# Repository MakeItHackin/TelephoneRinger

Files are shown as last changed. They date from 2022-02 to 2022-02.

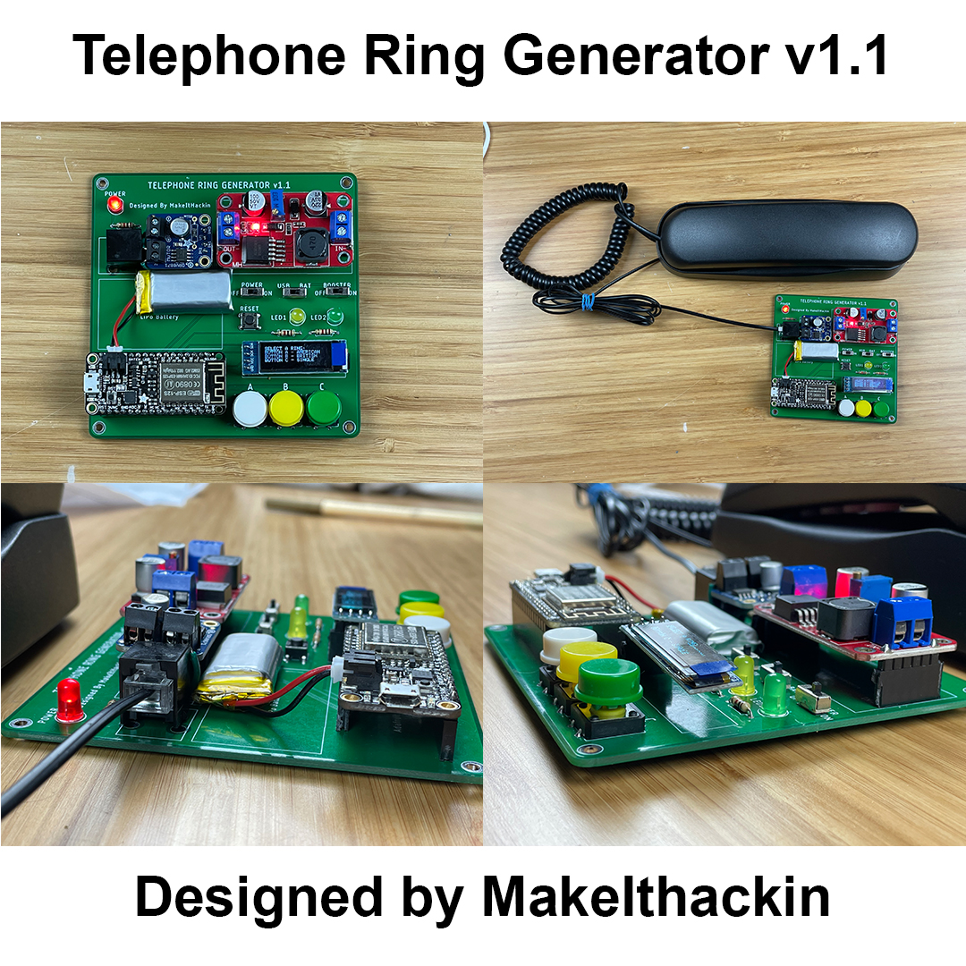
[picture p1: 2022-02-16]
TelephoneRingerV1.jpg

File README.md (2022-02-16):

# TelephoneRinger

This is a work in progress.... updates and more links to come!
If you have any suggestions, plase let me know by opening an Issue

Project offered under Attribution 4.0 International (CC BY 4.0) License.
  
Not all phone use the same amount of voltage/current to ring.  Seems like the really old phones may require higher wattage and this board may or may not ring them.  
  
BILL OF MATERIALS:
Adafruit Feather (Tested with RP2040, M0 Express, 32u4 Basic, and ESP8266 HUZZAH)  
LEDs 5mm - 3  
RESISTORS 1k - 3  
RJ-11 JACK - 1  
DRV8871 MOTOR CONTROLLER - 1  (https://www.adafruit.com/product/3190)  
XL6019 BOOST CONVERTER - 1  
SWITCHES - 3  
6mm BUTTON - 1  
12mm BUTTON - 3  
  
OPTIONAL:  
RESISTORS 10k - 3  
SSD1306 OLED (i2c) - 1  
FEMALE HEADERS FOR MODULES  
MALE HEADERS FOR MODULES  
LIPO BATTERY - 1
ADAFRUIT FEATHER WING  
TELEPHONE RING GENERATOR PCB

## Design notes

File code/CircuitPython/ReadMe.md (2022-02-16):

CircuitPython  
Tested Successfully on a Adafruit Feather RP2040  

Testing partially failed on Adafruit Feather M0 Express.  I could get the Telephone Ringer to work, but not in addition to the OLED.  I believe this occured from an out-of-memory error.  There's a variable to disable the OLED in the code.

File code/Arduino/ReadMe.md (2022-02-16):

Arduino code tested on Arduino build 1.8.13  
Optional variables to include an OLED Display (SSD1306 used in example) and Adafruit IO to remotely control ringer  

Tested on:  
Adafruit Feather Huzzah ESP8266  
Adafruit Feather 32u4 Basic  
Adafruit Feather M0 Express

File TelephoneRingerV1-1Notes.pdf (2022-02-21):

# Telephone Rigner v1.1 Notes

Ground was not connected on Feather Footprint, so after soldering Feather (or headers), use a wire and solder to the GND pin on the feather (4th from the right as shown) and connect it to any other Ground point on the board. (fixed in v1.2)
If your Feather does not have pull-up resistors on the appropriate button pins, you’ll need to solder one between that pin and VCC (fixed in v1.2)
If you don’t want to “commit” the modules to the PCB, use Female Headers as shown for the components. That way, you can swap them out later!
Photo of board bottom shows solder bridging on RJ-11 jack. This was intentional because a different jack was used than antipated. If you received a board, you should have the correct jack and no solder bridging is required.

XL6019 Board requires you to adjust the output voltage with the potentiometer. Test with a multimeter to see output. You should be able to get around 40VDC from when power is coming from the USB port.
POWER ON/OFF button only commands the Feather. It does not turn off power to the XL6019. USB/BAT selects either the USB or BAT power to send to the XL6019.
BOOSTER ON/OFF dis BOOSTER ON/OFF disconnects the USB/BAT power from entering the XL6019.
RESET is connected to RST pin of the Feather
Schematics PCB files for v1.2 are on github and the PCB will be released in March 2022

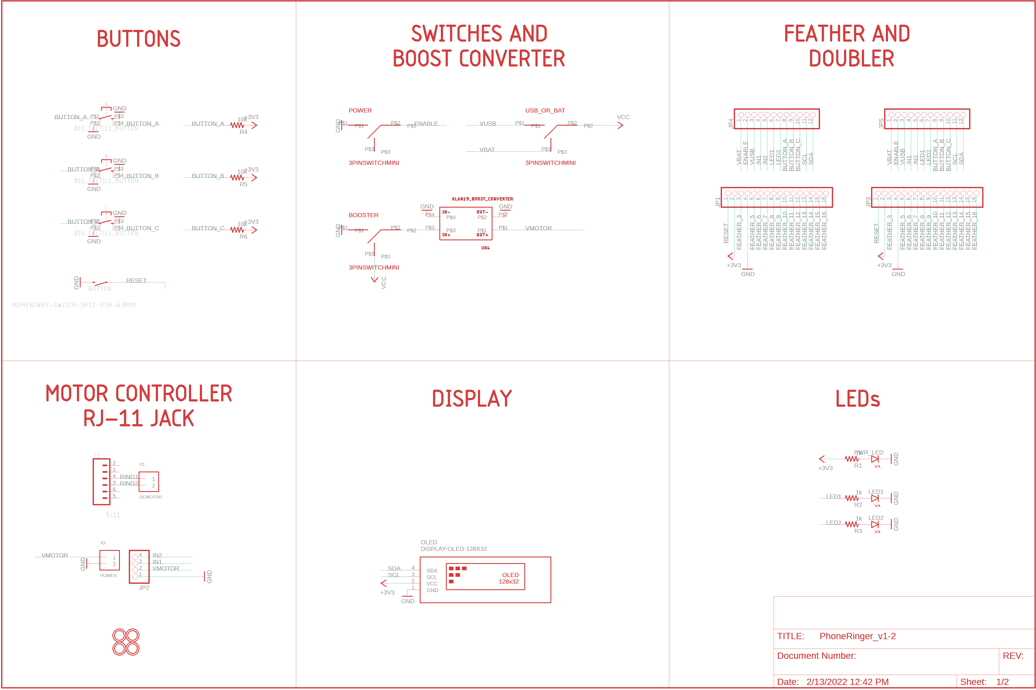
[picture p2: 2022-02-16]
PCBFiles/TelephoneRingerV1.2Schematic.png

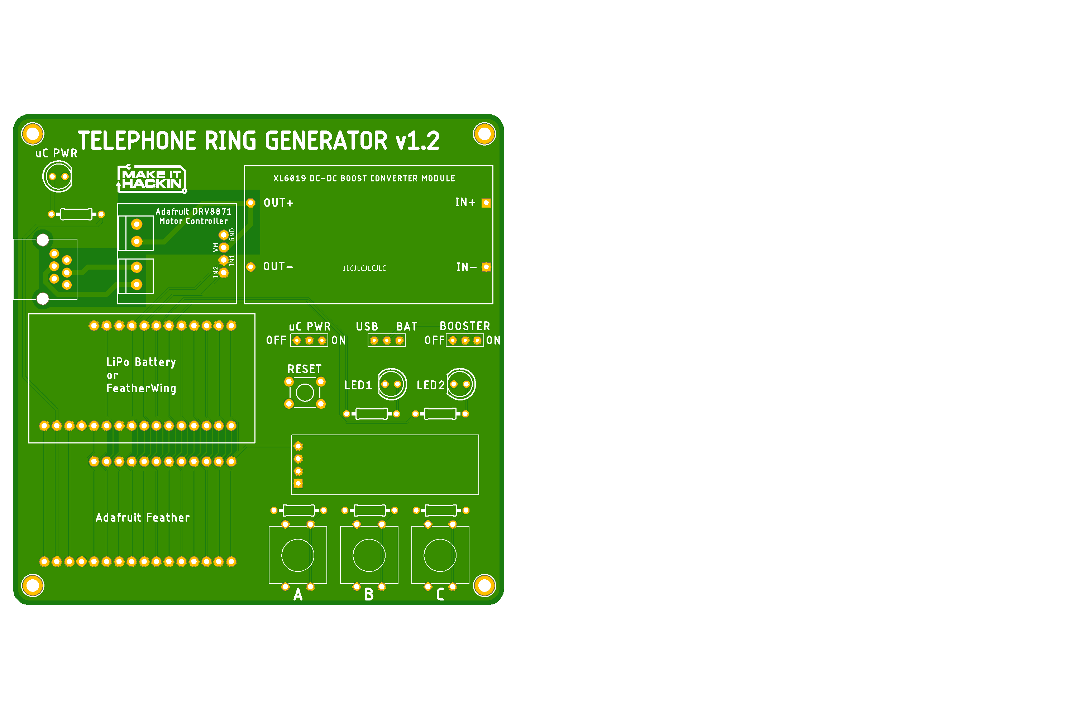
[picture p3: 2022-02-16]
PCBFiles/PhoneRinger_v1-2.png

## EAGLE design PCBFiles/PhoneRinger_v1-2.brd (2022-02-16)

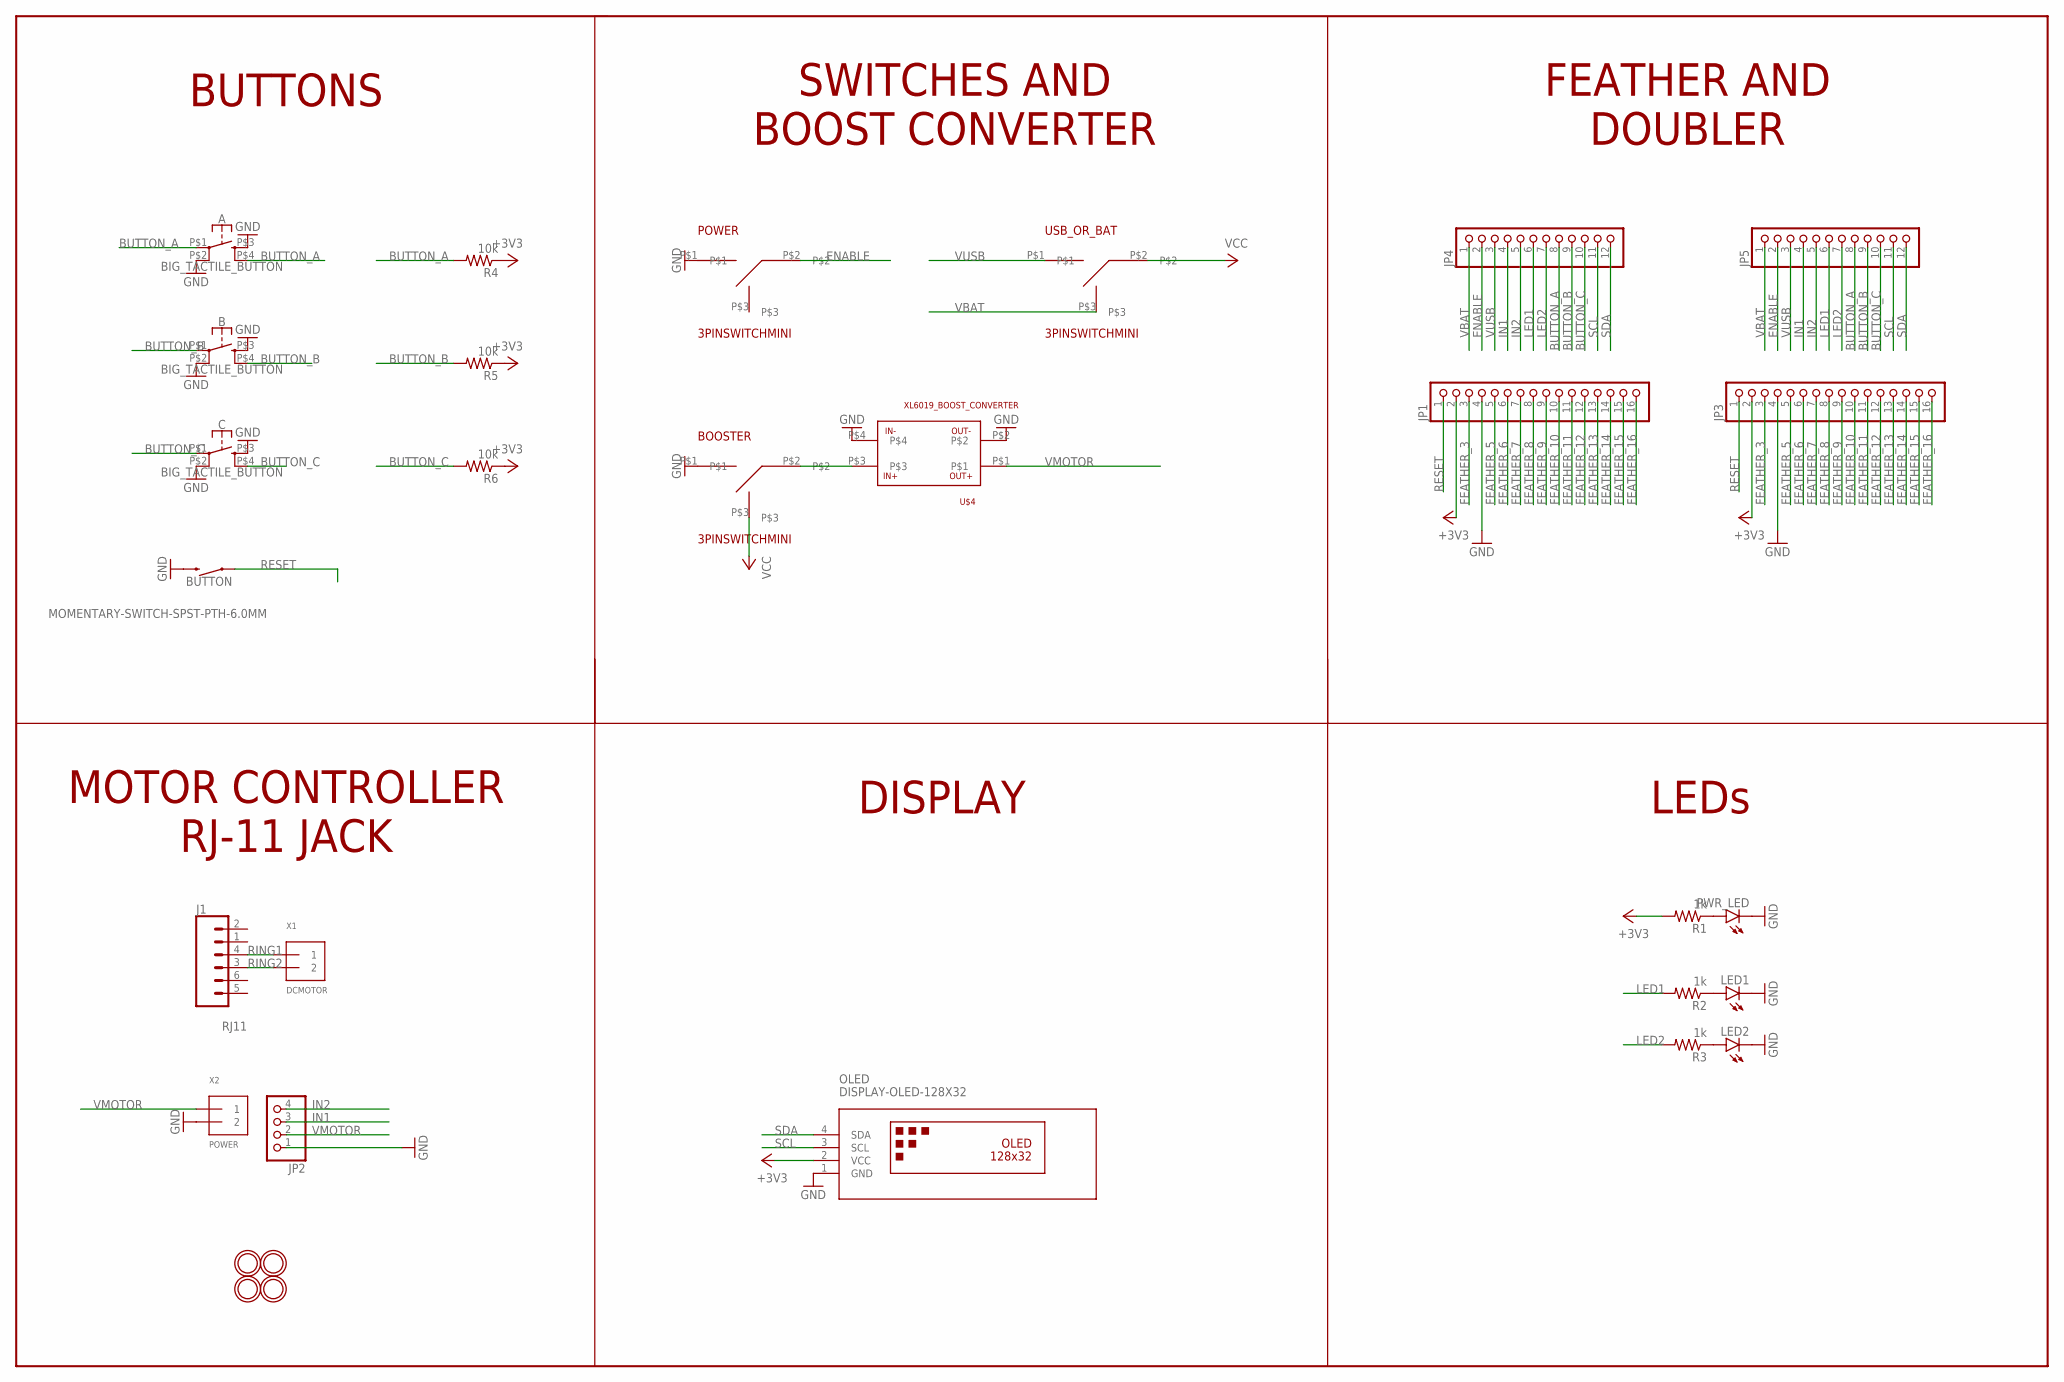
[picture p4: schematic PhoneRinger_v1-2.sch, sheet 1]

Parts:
A: BIG_TACTILE_BUTTON; BIG_TACTILE_BUTTON_FP
B: BIG_TACTILE_BUTTON; BIG_TACTILE_BUTTON_FP
BOOSTER: 3PINSWITCHMINI; 3PINMINI
BUTTON: MOMENTARY-SWITCH-SPST-PTH-6.0MM; TACTILE_SWITCH_PTH_6.0MM
C: BIG_TACTILE_BUTTON; BIG_TACTILE_BUTTON_FP
J1: RJ11; RJ11-6
JP1, JP3: HEADER-1X16_76MIL; 1X16_ROUND_76MIL
JP2: HEADER-1X476MIL; 1X04_ROUND_76
JP4, JP5: HEADER-1X1276MIL; 1X12_ROUND_76MIL
LED1, LED2: LED5MM
OLED: DISPLAY-OLED-128X32
POWER: 3PINSWITCHMINI; 3PINMINI
PWR_LED: LED5MM
R1, R2, R3: 1k; 0207/10
R4, R5, R6: 10k; 0207/10
U$4: XL6019_BOOST_CONVERTER; XL6019_FP
U$5, U$6, U$7, U$8: MICROBUILDER_MOUNTINGHOLE2.5_THICK; MICROBUILDER_MOUNTINGHOLE_2.5_PLATED_THICK
USB_OR_BAT: 3PINSWITCHMINI; 3PINMINI
X1: DCMOTOR; TERMBLOCK_1X2-3.5MM
X2: POWER; TERMBLOCK_1X2-3.5MM

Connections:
+3V3: JP1.2, JP3.2, OLED.2 (VCC), R1.2, R4.1, R5.1, R6.1
BUTTON_A: A.P$1 (1), A.P$4 (4), JP4.8, JP5.8, R4.2
BUTTON_B: B.P$1 (1), B.P$4 (4), JP4.9, JP5.9, R5.2
BUTTON_C: C.P$1 (1), C.P$4 (4), JP4.10, JP5.10, R6.2
ENABLE: JP4.2, JP5.2, POWER.P$2
FEATHER_3: JP1.3, JP3.3
FEATHER_5: JP1.5, JP3.5
FEATHER_6: JP1.6, JP3.6
FEATHER_7: JP1.7, JP3.7
FEATHER_8: JP1.8, JP3.8
FEATHER_9: JP1.9, JP3.9
FEATHER_10: JP1.10, JP3.10
FEATHER_11: JP1.11, JP3.11
FEATHER_12: JP1.12, JP3.12
FEATHER_13: JP1.13, JP3.13
FEATHER_14: JP1.14, JP3.14
FEATHER_15: JP1.15, JP3.15
FEATHER_16: JP1.16, JP3.16
GND: A.P$2 (2), A.P$3 (3), B.P$2 (2), B.P$3 (3), BOOSTER.P$1, BUTTON.3 (2), C.P$2 (2), C.P$3 (3), JP1.4, JP2.1, JP3.4, LED1.K (C), LED2.K (C), OLED.1 (GND), POWER.P$1, PWR_LED.K (C), U$4.P$2, U$4.P$4, X2.2
IN1: JP2.3, JP4.4, JP5.4
IN2: JP2.4, JP4.5, JP5.5
LED1: JP4.6, JP5.6, R2.2
LED2: JP4.7, JP5.7, R3.2
unnamed: PWR_LED.A, R1.1
unnamed: LED1.A, R2.1
unnamed: LED2.A, R3.1
unnamed: BOOSTER.P$2, U$4.P$3
RESET: BUTTON.1, JP1.1, JP3.1
RING1: J1.4, X1.1
RING2: J1.3, X1.2
SCL: JP4.11, JP5.11, OLED.3 (SCL)
SDA: JP4.12, JP5.12, OLED.4 (SDA)
VBAT: JP4.1, JP5.1, USB_OR_BAT.P$3
VCC: BOOSTER.P$3, USB_OR_BAT.P$2
VMOTOR: JP2.2, U$4.P$1, X2.1
VUSB: JP4.3, JP5.3, USB_OR_BAT.P$1

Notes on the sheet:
BUTTONS
SWITCHES AND BOOST CONVERTER
FEATHER AND DOUBLER
LEDs
DISPLAY
MOTOR CONTROLLER RJ-11 JACK

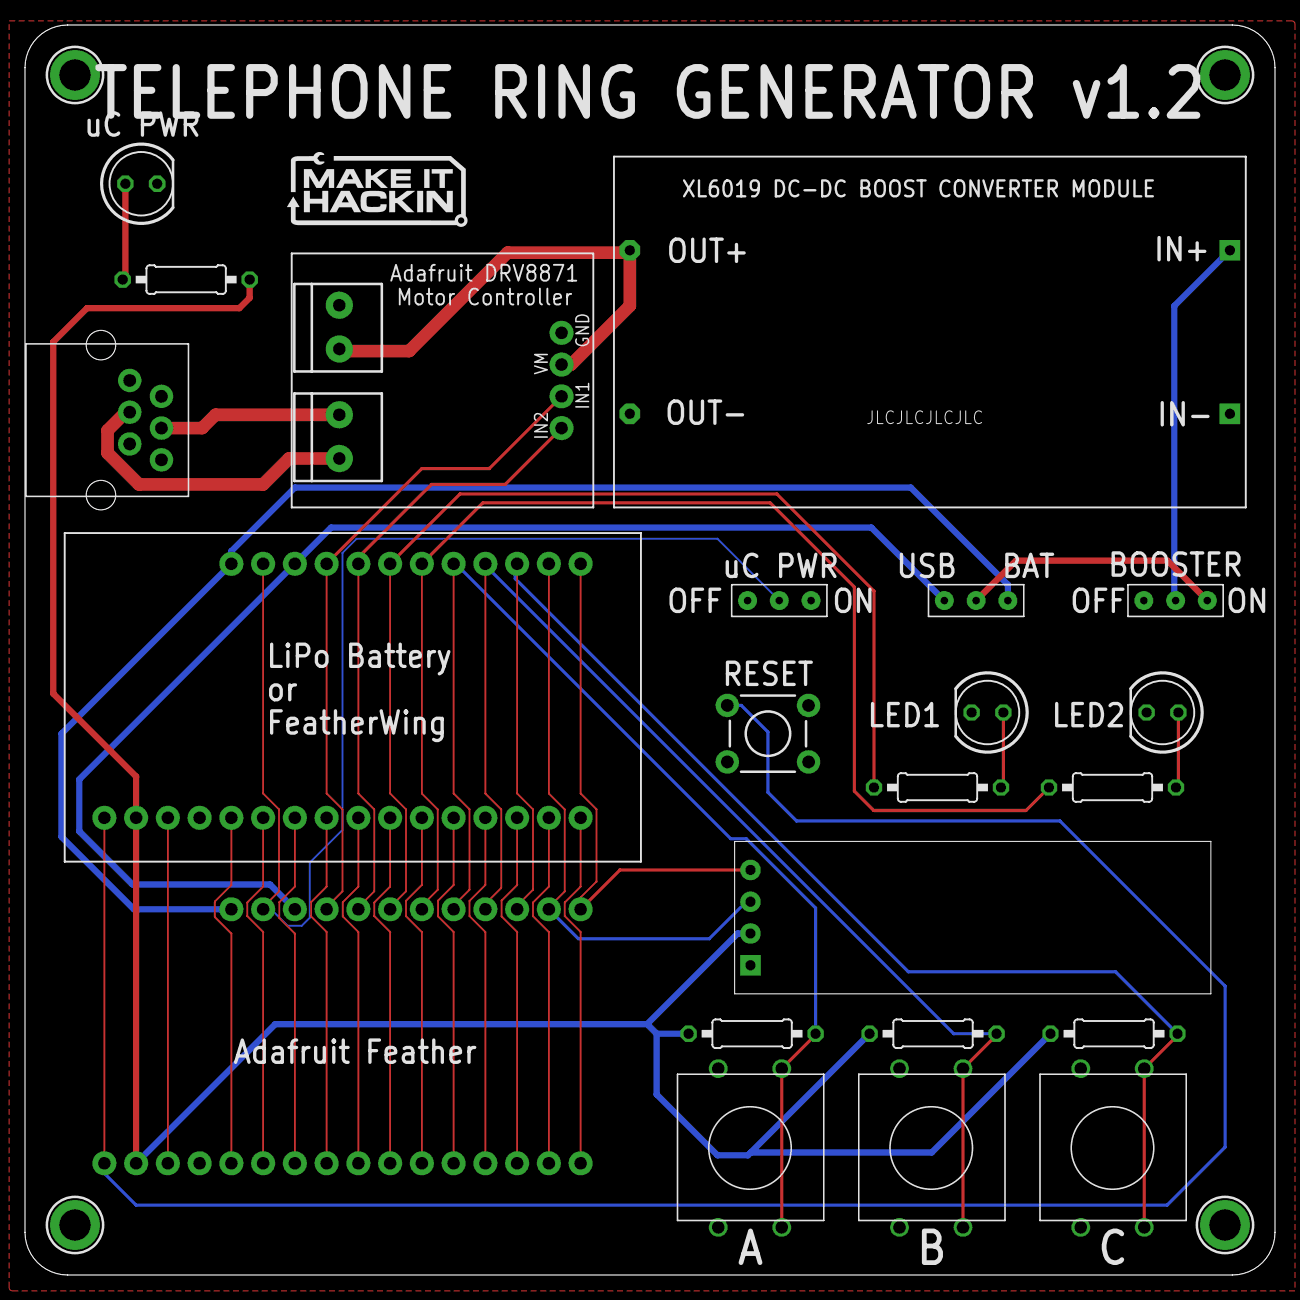
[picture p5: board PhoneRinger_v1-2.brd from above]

Board: 2 copper layers, 100.0 x 100.0 mm, 30 parts (0 on the bottom side), 36 nets.

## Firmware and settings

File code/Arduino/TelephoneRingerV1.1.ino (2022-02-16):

/*
 TELEPHONE RINGER BY MakeItHackin
 FOR MORE INFORMATION, VISIT: https://github.com/MakeItHackin/TelephoneRinger
 Version: 1.1 with Optional Display
 */



/**************************************************************************
 This is an example for our Monochrome OLEDs based on SSD1306 drivers

 Pick one up today in the adafruit shop!
 ------> http://www.adafruit.com/category/63_98

 This example is for a 128x32 pixel display using I2C to communicate
 3 pins are required to interface (two I2C and one reset).

 Adafruit invests time and resources providing this open
 source code, please support Adafruit and open-source
 hardware by purchasing products from Adafruit!

 Written by Limor Fried/Ladyada for Adafruit Industries,
 with contributions from the open source community.
 BSD license, check license.txt for more information
 All text above, and the splash screen below must be
 included in any redistribution.
 **************************************************************************/

#define OLEDSCREEN //false // set true for using a SSD1306 OLED Display
#define ADAFRUIT_IO // false // set true to connect to and control board using Adafruit IO

#if ADAFRUIT_IO == true
  #include "config.h" // config file for wifi credentials
  // set up the 'digital' feed
  AdafruitIO_Feed *RingFeed = io.feed("RingFeed");
  AdafruitIO_Feed *BritishRingFeed = io.feed("BritishRingFeed");
  AdafruitIO_Feed *SingleRingFeed = io.feed("SingleRingFeed");
#endif

#if OLEDSCREEN == true
  #include <SPI.h>
  #include <Wire.h>
  #include <Adafruit_GFX.h>
  #include <Adafruit_SSD1306.h>

  #define SCREEN_WIDTH 128 // OLED display width, in pixels
  #define SCREEN_HEIGHT 32 // OLED display height, in pixels
  
  // Declaration for an SSD1306 display connected to I2C (SDA, SCL pins)
  #define OLED_RESET     -1 // Reset pin # (or -1 if sharing Arduino reset pin)
  Adafruit_SSD1306 display(SCREEN_WIDTH, SCREEN_HEIGHT, &Wire, OLED_RESET);
  
  // ADAFRUIT LOGO
  static const unsigned char PROGMEM logo_bmp[] =
  { B00000000, B11000000,
    B00000001, B11000000,
    B00000001, B11000000,
    B00000011, B11100000,
    B11110011, B11100000,
    B11111110, B11111000,
    B01111110, B11111111,
    B00110011, B10011111,
    B00011111, B11111100,
    B00001101, B01110000,
    B00011011, B10100000,
    B00111111, B11100000,
    B00111111, B11110000,
    B01111100, B11110000,
    B01110000, B01110000,
    B00000000, B00110000 };
#endif

// PIN ASSIGNMENTS FOR A,B,C BUTTONS, MOTOR CONTROLLER, AND LEDS
#if defined(ESP8266)
  #define BUTTON_A  0
  #define BUTTON_B 16
  #define BUTTON_C  2
  #define IN1 14
  #define IN2 12
  #define LED1 13
  #define LED2 15
#elif defined(ESP32)
  #define BUTTON_A 15
  #define BUTTON_B 32
  #define BUTTON_C 14
  #define IN1 13
  #define IN2 12
  #define LED1 27
  #define LED2 33
#elif defined(ARDUINO_STM32_FEATHER)
  #define BUTTON_A PA15
  #define BUTTON_B PC7
  #define BUTTON_C PC5
  #define IN1 PB5
  #define IN2 PA13
  #define LED1 PA4
  #define LED2 PB4
#elif defined(TEENSYDUINO)
  #define BUTTON_A  4
  #define BUTTON_B  3
  #define BUTTON_C  8
  #define IN1 5
  #define IN2 6
  #define LED1 9
  #define LED2 10
#elif defined(ARDUINO_FEATHER52832)
  #define BUTTON_A 31
  #define BUTTON_B 30
  #define BUTTON_C 27
  #define IN1 16
  #define IN2 15
  #define LED1 7
  #define LED2 11
#else // 32u4, M0, M4, nrf52840 and 328p
  #define BUTTON_A  9
  #define BUTTON_B  6
  #define BUTTON_C  5
  #define IN1 13
  #define IN2 12
  #define LED1 11
  #define LED2 10
#endif


// LOOP COUNT FOR AMERICAN RINGER
// HIGHER VALUE INCREASES RING DURATION
int americanLoopCount = 30; 

// LOOP DELAY FOR AMERICAN RINGER
// A VALUE OF 25 WILL PRODUCE 20 HERTZ.  YOU PROBABLY DON'T NEED TO CHANGE THIS VALUE. SOME PHONES WILL NOT RING WITH VALUES BEYOND A COUPLE HERTZ.
int americanLoopDelay = 26;  

// LOOP COUNT FOR BRITISH RINGER
// HIGHER VALUE INCREASES RING DURATION
int britishLoopCount = 10;

// LOOP DELAY FOR BRITISH RINGER
// THE DEFAULT VALUE OF 19 IS PRETTY LOW AND MAY NOT WORK ON ALL PHONES 
int britishLoopCountDelay = 19;

// DELAY BETWEEN RINGS FOR BRITISH RINGER
// FEEL FREE TO EXPERIMENT WITH THIS VALUE
int britishDelayBetweenRings = 200;


void setup() {
  // put your setup code here, to run once:
  Serial.begin(9600);

  // SETTING UP PIN DIRECTION
  pinMode(IN1, OUTPUT);
  pinMode(IN2, OUTPUT);
  pinMode(LED1, OUTPUT);
  pinMode(LED2, OUTPUT);
  pinMode(BUTTON_A, INPUT_PULLUP);
  pinMode(BUTTON_B, INPUT_PULLUP);
  pinMode(BUTTON_C, INPUT_PULLUP);
  
  #if OLEDSCREEN == true
    if(!display.begin(SSD1306_SWITCHCAPVCC, 0x3C)) { // Address 0x3C for 128x32
      Serial.println(F("SSD1306 allocation failed"));
      for(;;); // Don't proceed, loop forever
    }
    display.display(); // ADAFRUIT LOGO
    // Clear the buffer
    display.clearDisplay();
    display.setTextSize(1);             // Normal 1:1 pixel scale
    display.setTextColor(WHITE);        // Draw white text
  #endif

  #if ADAFRUIT_IO == true
    // wait for serial monitor to open
    while(! Serial);
    // connect to io.adafruit.com
    Serial.print("Connecting to Adafruit IO");
    #if OLEDSCREEN == true
      display.setCursor(0,0);             // Start at top-left corner
      display.println(F("CONNECTING TO"));
      display.println(F("ADAFRUIT IO..."));
      display.display();
    #endif
    io.connect();
    // set up a message handler for the 'digital' feed.
    // the handleMessage function (defined below)
    // will be called whenever a message is
    // received from adafruit io.
    RingFeed->onMessage(handleMessage);
    BritishRingFeed->onMessage(handleBritish);
    SingleRingFeed->onMessage(handleSingle); 
    // wait for a connection
    while(io.status() < AIO_CONNECTED) {
      Serial.print(".");
      delay(500);
    }
      // we are connected
    Serial.println();
    Serial.println(io.statusText());
    RingFeed->get();
    BritishRingFeed->get();
    SingleRingFeed->get();
  #endif
  
  Serial.println("Starting...");
}

void loop() {
  #if ADAFRUIT_IO == true
    io.run();
  #endif
  
  #if OLEDSCREEN == true
    displayRingMenu(); // DISPLAY RING MENU
  #endif
  // ASSIGN BUTTON INPUTS TO BOOLEAN VALUES
  bool buttonAState = digitalRead(BUTTON_A);
  bool buttonBState = digitalRead(BUTTON_B);
  bool buttonCState = digitalRead(BUTTON_C);

  if (buttonAState == LOW){  // BUTTON A PRESSED
    displayButtonPress('A');
    ringTelephone(2,1000,30,26,false,1);
  }
  else if (buttonBState == LOW){ // BUTTON B PRESSED
    displayButtonPress('b');  
    ringTelephone(3,1000,10,19,true,2);   
  }
  else if (buttonCState == LOW){ // BUTTON C PRESSED
    displayButtonPress('c');  
    ringTelephone(1,0,4,26,false,2);    
  }
  else{
    digitalWrite(LED1, LOW);
    digitalWrite(LED2, LOW);
  }
}

#if OLEDSCREEN == true
  // THIS MENU WILL BE DISPLAYED WHEN USER IS NOT PRESSING BUTTONS
  void displayRingMenu(){
    display.clearDisplay();
    display.setCursor(0,0);             // Start at top-left corner
    display.println(F("SELECT A RING:"));
    display.println(F("BUTTON A - AMERICAN"));
    display.println(F("BUTTON B - BRITISH"));
    display.println(F("BUTTON C - SINGLE"));
    display.display();
  }
#endif

// WHEN A USER PRESSES BUTTONS THESE SCREENS WILL APPEAR
void displayButtonPress(char button){
  if (button == 'a' || button == 'A'){
    Serial.println("BUTTON A PRESSED!");
    #if OLEDSCREEN == true
      display.clearDisplay();
      display.setCursor(0,0);             // Start at top-left corner
      display.println(F("BUTTON A PRESSED"));
      display.println(F("AMERICAN RING!"));
      display.display();
    #endif
  }
  else if (button == 'b' || button == 'B'){
    Serial.println("BUTTON B PRESSED!");
    #if OLEDSCREEN == true
      display.clearDisplay();
      display.setCursor(0,0);             // Start at top-left corner
      display.println(F("BUTTON B PRESSED"));
      display.println(F("BRITISH RING!"));
      display.display();
    #endif
  }
  else if (button == 'c' || button == 'C'){
    Serial.println("BUTTON C PRESSED!");
    #if OLEDSCREEN == true
      display.clearDisplay();
      display.setCursor(0,0);             // Start at top-left corner
      display.println(F("BUTTON C PRESSED"));
      display.println(F("SINGLE RING!"));
      display.display();
    #endif
  }
}

// THIS FUNCTION IS USED TO RING THE TELEPHONE USING GIVEN PARAMETERS
// ringCount: This is how many times you want the phone to ring
// ringDelay: This is the amount of milliseconds you want between each ring
// loopCount: This is how long the phone should ring during one ring.
// loopDelay: This corresponds to the frequency of the ring.  You'll need to stay around 25 +- 6
// britishBoolean: true for "British" style ring or false for "American" style
// ledAssignment: 1 for LED1 or 2 for LED2

void ringTelephone (int ringCount, int ringDelay, int loopCount, int loopDelay, bool britishBoolean, byte ledAssignment){
  int interation = 1;
  Serial.print("ringCount: ");
  Serial.print(ringCount);
  Serial.print(" - ringDelay: ");
  Serial.print(ringDelay);
  Serial.print(" - loopCount: ");
  Serial.print(loopCount);
  Serial.print(" - loopDelay: ");
  Serial.print(loopDelay);
  Serial.print(" - britishBoolean: ");
  Serial.print(britishBoolean);
  Serial.print(" - ledAssignment: ");
  Serial.println(ledAssignment);
  
  for(int i = 0; i < ringCount; i++){
    if (ledAssignment == 1){
      digitalWrite(LED1, HIGH);
    }
    else {
      digitalWrite(LED2, HIGH);
    }
    
    if (britishBoolean == true){
      interation = 2; // "British" rings are two quick rings, so setting up a loop to ring twice
    }
    for (int j = 0; j < interation; j++){ // this for loop is for the american or british ring styles
      for(int x = 0; x < loopCount; x++){ // this for loop is for the duration of the ring.
        //Serial.println("loop");
        digitalWrite(IN1, HIGH);
        digitalWrite(IN2, LOW);
        delay(loopDelay);
        digitalWrite(IN1, LOW);
        digitalWrite(IN2, HIGH);
        delay(loopDelay);
      }
      if (britishBoolean == true){ // for the british ring, delay a little bit before the next quick ring
        delay(britishDelayBetweenRings);
      }
    }
    if (ledAssignment == 1){ // turn off the led at the end of each ring
      digitalWrite(LED1, LOW);
    }
    else {
      digitalWrite(LED2, LOW);
    }
    delay(ringDelay);
  }
  delay(100);
}


#if ADAFRUIT_IO == true
  // this function is called whenever an 'digital' feed message
  // is received from Adafruit IO. it was attached to
  // the 'digital' feed in the setup() function above.
  void handleMessage(AdafruitIO_Data *American_Ring) {
  
    Serial.print("received <- ");
  
    if(American_Ring->toPinLevel() == HIGH){
      Serial.println("AMERICAN HIGH");
    }
    else {
      Serial.println("AMERICAN LOW");
      display.clearDisplay();
      display.setCursor(0,0);             // Start at top-left corner
      display.println(F("IO BUTTON A PRESSED"));
      ringTelephone(1,1000,30,26,false,1);
    }
 // digitalWrite(LED_PIN, American_Ring->toPinLevel());
}
#endif

#if ADAFRUIT_IO == true
void handleBritish(AdafruitIO_Data *data) {

  Serial.print("received <- ");

  if(data->toPinLevel() == HIGH){
    Serial.println("BRITISH HIGH");
  }
  else {
    Serial.println("BRITISH LOW");
    display.clearDisplay();
    display.setCursor(0,0);             // Start at top-left corner
    display.println(F("IO BUTTON B PRESSED"));
    ringTelephone(1,1000,10,19,true,2); 
  }
//  digitalWrite(LED_PIN, data->toPinLevel());
}
#endif

#if ADAFRUIT_IO == true
void handleSingle(AdafruitIO_Data *data) {

  Serial.print("received <- ");

  if(data->toPinLevel() == HIGH){
    Serial.println("SINGLE HIGH");
  }
  else {
    Serial.println("SINGLE LOW");
    display.clearDisplay();
    display.setCursor(0,0);             // Start at top-left corner
    display.println(F("IO BUTTON C PRESSED"));
    ringTelephone(1,0,4,26,false,2);
  }
//  digitalWrite(LED_PIN, data->toPinLevel());
}
#endif

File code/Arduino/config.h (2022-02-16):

/************************ Adafruit IO Config *******************************/

// visit io.adafruit.com if you need to create an account,
// or if you need your Adafruit IO key.
#define IO_USERNAME "YOURUSERNAME"
#define IO_KEY "APIKEY"

/******************************* WIFI **************************************/

// the AdafruitIO_WiFi client will work with the following boards:
//   - HUZZAH ESP8266 Breakout -> https://www.adafruit.com/products/2471
//   - Feather HUZZAH ESP8266 -> https://www.adafruit.com/products/2821
//   - Feather HUZZAH ESP32 -> https://www.adafruit.com/product/3405
//   - Feather M0 WiFi -> https://www.adafruit.com/products/3010
//   - Feather WICED -> https://www.adafruit.com/products/3056
//   - Adafruit PyPortal -> https://www.adafruit.com/product/4116
//   - Adafruit Metro M4 Express AirLift Lite ->
//   https://www.adafruit.com/product/4000
//   - Adafruit AirLift Breakout -> https://www.adafruit.com/product/4201
//   - Adafruit AirLift Shield -> https://www.adafruit.com/product/4285
//   - Adafruit AirLift FeatherWing -> https://www.adafruit.com/product/4264

#define WIFI_SSID "YOURWIFI"
#define WIFI_PASS "YOURWIFIPASSWORD"

// uncomment the following line if you are using airlift
// #define USE_AIRLIFT

// uncomment the following line if you are using winc1500
// #define USE_WINC1500

// uncomment the following line if you are using mrk1010 or nano 33 iot
//#define ARDUINO_SAMD_MKR1010

// comment out the following lines if you are using fona or ethernet
#include "AdafruitIO_WiFi.h"

#if defined(USE_AIRLIFT) || defined(ADAFRUIT_METRO_M4_AIRLIFT_LITE) ||         \
    defined(ADAFRUIT_PYPORTAL)
// Configure the pins used for the ESP32 connection
#if !defined(SPIWIFI_SS) // if the wifi definition isnt in the board variant
// Don't change the names of these #define's! they match the variant ones
#define SPIWIFI SPI
#define SPIWIFI_SS 10 // Chip select pin
#define NINA_ACK 9    // a.k.a BUSY or READY pin
#define NINA_RESETN 6 // Reset pin
#define NINA_GPIO0 -1 // Not connected
#endif
AdafruitIO_WiFi io(IO_USERNAME, IO_KEY, WIFI_SSID, WIFI_PASS, SPIWIFI_SS,
                   NINA_ACK, NINA_RESETN, NINA_GPIO0, &SPIWIFI);
#else
AdafruitIO_WiFi io(IO_USERNAME, IO_KEY, WIFI_SSID, WIFI_PASS);
#endif
/******************************* FONA **************************************/

// the AdafruitIO_FONA client will work with the following boards:
//   - Feather 32u4 FONA -> https://www.adafruit.com/product/3027

// uncomment the following two lines for 32u4 FONA,
// and comment out the AdafruitIO_WiFi client in the WIFI section
// #include "AdafruitIO_FONA.h"
// AdafruitIO_FONA io(IO_USERNAME, IO_KEY);

/**************************** ETHERNET ************************************/

// the AdafruitIO_Ethernet client will work with the following boards:
//   - Ethernet FeatherWing -> https://www.adafruit.com/products/3201

// uncomment the following two lines for ethernet,
// and comment out the AdafruitIO_WiFi client in the WIFI section
// #include "AdafruitIO_Ethernet.h"
// AdafruitIO_Ethernet io(IO_USERNAME, IO_KEY);

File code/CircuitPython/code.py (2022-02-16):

'''
 TELEPHONE RINGER BY MakeItHackin
 FOR MORE INFORMATION, VISIT: https://github.com/MakeItHackin/TelephoneRinger
 Version: 1.1 with Optional Display
'''
# DISPLAY CODE PROVIDED BY ADAFRUIT
# SPDX-FileCopyrightText: 2021 ladyada for Adafruit Industries
# SPDX-License-Identifier: MIT

useOLEDDisplay = True  #set true for using a SSD1306 OLED Display

import board
import time
import digitalio

if (useOLEDDisplay == True):
    import displayio
    import terminalio
    from adafruit_display_text import label
    import adafruit_displayio_ssd1306

print("Starting...")


#SETTING UP PIN ASSIGNMENTS AND DIRECTIONS.  TESTED ON ADAFRUIT FEATHER RP2040.  YOU MAY NEED TO CHANGE THESE PINS.

#MOTOR CONTROLLER
in1 = digitalio.DigitalInOut(board.D13)
in1.direction = digitalio.Direction.OUTPUT
in2 = digitalio.DigitalInOut(board.D12)
in2.direction = digitalio.Direction.OUTPUT

#LEDS
led1 = digitalio.DigitalInOut(board.D11)
led1.direction = digitalio.Direction.OUTPUT
led2 = digitalio.DigitalInOut(board.D10)
led2.direction = digitalio.Direction.OUTPUT

#BUTTONS
button_A = digitalio.DigitalInOut(board.D9)
button_A.direction = digitalio.Direction.INPUT
button_A.pull = digitalio.Pull.UP

button_B = digitalio.DigitalInOut(board.D6)
button_B.direction = digitalio.Direction.INPUT
button_B.pull = digitalio.Pull.UP

button_C = digitalio.DigitalInOut(board.D5)
button_C.direction = digitalio.Direction.INPUT
button_C.pull = digitalio.Pull.UP

# LOOP COUNT FOR AMERICAN RINGER
# HIGHER VALUE INCREASES RING DURATION
americanLoopCount = 30

# LOOP DELAY FOR AMERICAN RINGER
# A VALUE OF 25 WILL PRODUCE 20 HERTZ.  YOU PROBABLY DON'T NEED TO CHANGE THIS VALUE. SOME PHONES WILL NOT RING WITH VALUES BEYOND A COUPLE HERTZ.
americanDelay = .026

# LOOP COUNT FOR BRITISH RINGER
# HIGHER VALUE INCREASES RING DURATION
britishLoopCount = 10

# LOOP DELAY FOR BRITISH RINGER
# THE DEFAULT VALUE OF .019 IS PRETTY LOW AND MAY NOT WORK ON ALL PHONES 
britishDelay = .019

# DELAY BETWEEN RINGS FOR BRITISH RINGER
# FEEL FREE TO EXPERIMENT WITH THIS VALUE
britishDelayBetweenRings = .2

# WHEN A USER PRESSES BUTTONS THESE SCREENS WILL APPEAR
def displayButtonPress(button):  
    if (button == 'a' or button == 'A'):
        print("BUTTON A PRESSED!")
    elif (button == 'b' or button == 'B'):
        print("BUTTON B PRESSED!")
    elif (button == 'c' or button == 'C'):
        print("BUTTON C PRESSED!")

    if (useOLEDDisplay == True):
        bg_sprite = displayio.TileGrid(color_bitmap, pixel_shader=color_palette, x=0, y=0)
        splash.append(bg_sprite)
        if (button == 'a' or button == 'A'):
            textA = "BUTTON A PRESSED\nAMERICAN RING!"
        elif (button == 'b' or button == 'B'):
            textA = "BUTTON B PRESSED\nBRITISH RING!"
        elif (button == 'c' or button == 'C'):
            textA = "BUTTON C PRESSED\nSINGLE RING!"
        text_areaA = label.Label(terminalio.FONT, text=textA, color=0xFFFF00, background_color = 0x000000, x=0, y=5, line_spacing = 1, scale = 1)
        splash.append(text_areaA)
        display.show(splash)
    return

'''
    THIS FUNCTION IS USED TO RING THE TELEPHONE USING GIVEN PARAMETERS
    ringCount: This is how many times you want the phone to ring
    ringDelay: This is the amount of milliseconds you want between each ring
    loopCount: This is how long the phone should ring during one ring.
    loopDelay: This corresponds to the frequency of the ring.  You'll need to stay around 25 +- 6
    britishBoolean: true for "British" style ring or false for "American" style
    ledAssignment: 1 for LED1 or 2 for LED2
'''
def ringTelephone(ringCount, ringDelay, loopCount, loopDelay, britishBoolean, ledAssignment):
    iteration = 1
    print("ringCount:", ringCount,"- ringDelay:", ringDelay,"- loopCount:",loopCount,"- loopDelay:",loopDelay,"- britishBoolean:",britishBoolean,"- ledAssignment:",ledAssignment)
    for i in range(ringCount):
        if (ledAssignment == 1):
            led1.value = True
        else:
            led2.value = True
        if (britishBoolean == True):
            iteration = 2 # "British" rings are two quick rings, so setting up a loop to ring twice
        for j in range(iteration): # this for loop is for the american or british ring styles
            for x in range(loopCount): #this for loop is for the duration of the ring.
                in1.value = True
                in2.value = False
                time.sleep(loopDelay)
                in1.value = False
                in2.value = True
                time.sleep(loopDelay)
            if (britishBoolean == True):
                time.sleep(britishDelayBetweenRings) # for the british ring, delay a little bit before the next quick ring
        if (ledAssignment == 1): # turn off the led at the end of each ring
            led1.value = False
        else:
            led2.value = False
        time.sleep(ringDelay)
    time.sleep(.1)
    print("done ringing")
    return

# THIS MENU WILL BE DISPLAYED WHEN USER IS NOT PRESSING BUTTONS
if (useOLEDDisplay == True): 
    def displayMenu():
        text1 = "BUTTON A - AMERICAN\nBUTTON B - BRITISH\nBUTTON C - SINGLE"
        text_area1 = label.Label(terminalio.FONT, text=text1, color=0xFFFF00, background_color = 0x000000, x=0, y=5, line_spacing = 0.8, scale = 1)
        splash.append(text_area1)
        display.show(splash)
        return

# SETTING UP THE DISPLAY
if (useOLEDDisplay == True):    
    displayio.release_displays()
    i2c = board.I2C()
    display_bus = displayio.I2CDisplay(i2c, device_address=0x3C)
    display = adafruit_displayio_ssd1306.SSD1306(display_bus, width=128, height=32)
    # Make the display context
    splash = displayio.Group()
    display.show(splash)
    color_bitmap = displayio.Bitmap(128, 32, 1)
    color_palette = displayio.Palette(1)
    color_palette[0] = 0xFFFFFF  # White
    color_palette[0] = 0x000000 # Black
    bg_sprite = displayio.TileGrid(color_bitmap, pixel_shader=color_palette, x=0, y=0)
    splash.append(bg_sprite)
    displayMenu()

# MAIN FUNCTION HERE.  WHEN THE USER PRESSES A BUTTON, THE EVENTS ARE PRINTED, PHONE RINGS, AND DISPLAY IS UPDATED 
while True:
    if (button_A.value == False):
        displayButtonPress('a')
        ringTelephone(2,1,30,.026,False,1) # 'American Ring'
        if (useOLEDDisplay == True):
            displayMenu()
    elif (button_B.value == False):
        displayButtonPress('b')
        ringTelephone(3,1,10,.019,True,2) # 'British Ring'
        if (useOLEDDisplay == True):
            displayMenu()
    elif (button_C.value == False):
        displayButtonPress('c')
        ringTelephone(1,0,4,.026,False,2) # 'Single Ring'
        if (useOLEDDisplay == True):
            displayMenu()
    else:
        led1.value = False # turn off LEDs
        led2.value = False

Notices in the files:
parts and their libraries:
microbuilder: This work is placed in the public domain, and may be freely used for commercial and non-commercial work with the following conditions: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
